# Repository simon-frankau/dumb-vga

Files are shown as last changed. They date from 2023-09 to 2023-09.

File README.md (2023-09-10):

# A simple flash-based VGA display

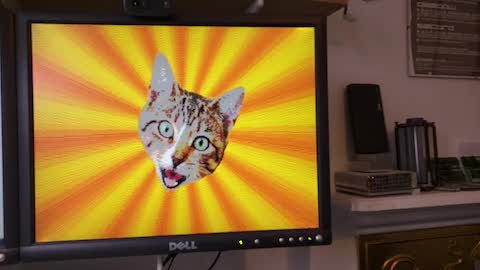
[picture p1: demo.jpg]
A picture of a cat's head, surrounded by a kind of sunburst pattern, being displayed on a montior


The idea of this project is to generate a basic VGA-like signal that a
monitor will display by putting the signal in a flash memory, and then
using counters to run through the address space. Simple, eh?

## VGA signal timing

We have h-sync and v-sync signals, with their respective front and
back porches. The main trick is the find a resolution that fits nicely
into a flash memory, so that the flash memory is a multiple of the
screen size - not the visible screen size, but the screen size with
all the sync bits.

A bit of twiddling gives a 384x240 visible display that is 512x256
once all the sync etc. is factored in.

## Clocking

A 32MHz clock is used as a dot clock for a 768x480 image at 60 FPS
(1024x512 when sync signals are factored in). The Flash cannot handle
a 32MHz data rate, but we clock it every other cycle and do scan-line
doubling to display a 384x240 image.

## VGA levels

H- and V-sync signals are straightforward to produce, as they're
apparently supposed to be TTL. That leaves 6 bits for 3 channels of
colour, or 2 bits per channel. A pair of resistors on each channel
makes the world's simplest DAC, with values chosen to give a 0.7V peak
when terminated by a 75 ohm resistor when both bits are set.

## Test pattern

gen_test.lua generates a simple RGB "checkerboard" displaying the
range of available colours.

gen_rom.lua generates a ROM image given a Gimp .data file (I couldn't
find a nice low-dep Lua image library). It simply takes the top two
bits of each pixel value to generate the colour.

prep_img.lua converts a .data image into another .data image that uses
the 6-bit colour space that the circuit can display. It uses dithering
to improve the generated image. Generating a ROM image from an image
that has been prepared with 'prep_img' should produce a rather better
result.

## Circuit design

The circuit breadboarded so far has three chained 74HC counters
supplying the address to a 29040 flash chip. A 74HC574 latches the
values for the display. (A 74HC574 triggers on the wrong edge to avoid
transients, but it's what I had to hand, and seems to work fine.)

## PCB

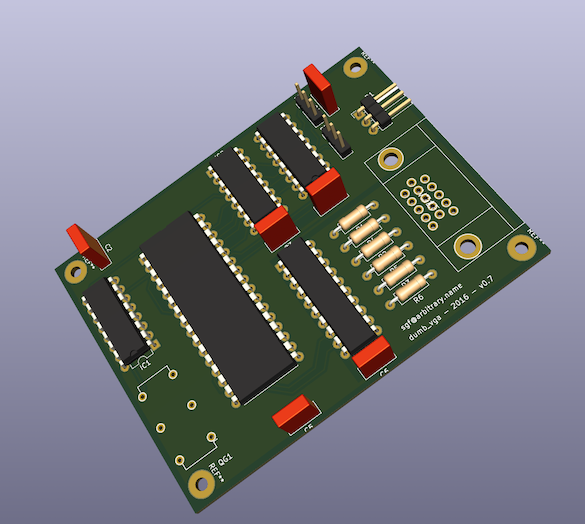
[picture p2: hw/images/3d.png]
A 3D render of the PCB


I sent the files in hw/gerbers to http://smart-prototyping.com/, and
they quickly sent me back PCBs which did the job. There are PDFs of
the Gerbers in hw/images.

### Assembly notes

The PCB is pretty straightforward to assemble (no surface mount!) as
long as you pay attention to the orientations, as I oriented things to
make routing easy, rather than assembly.

There should be enough space for a ZIF for the flash chip, although I
only used an IC socket.

The PCB has been designed to support 8-pin-sized oscillators as well
as 14-pin-sized oscillators. However, I installed the larger size.
Take a careful look at the PCB to see how to install the smaller
crystal if that's what you have. Check that power and ground reach the
appropriate pins.

Note that pin 1 of the power connector is ground, and pin 3 is Vcc.
This is something I wasn't paying attention to when setting up the
schematic (nor did I label it on the silkscreen).

### Animation speed

There are two headers on the board that you can jumper to set the
animation speed. They look like this:

```
 . . .   . . .
   P3      P2
```

The possibilities are:

```
 === .   === . Slow

 === .   . === Medium

 . ===   . === Fast
```

Note that only "medium" displays the 4 frames in the order they are in
memory (i.e. 1 2 3 4 1 2 3 4 ...). In the other two modes, the order
is 1 3 2 4 1 3 2 4 ... (if you're wondering why, it's because the
2-bit counter is bit-reversed). You will need to take this into
account when programming your animations.

## ROM image generation

The 'build.sh' script will generate a nice spinny [Bad Advice
cat](http://knowyourmeme.com/memes/bad-advice-cat) ROM image. If
you're using medium-speed mode, you'll need to pass the 'swap' flag.

I was originally hoping to script up the image wrangling mostly in
Gimp, but it turns out the script-fu support is rubbish. You can't
even [load a raw .data file in a non-interactive
script](https://github.com/marcelteun/GIMP-raw-file-load/blob/5f02e7607b1645d54b11bb9f01d44e362abca2d1/file-raw-load.c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).
So, it's just raw data files.

cat.data.gz was generated from cat.png using the Gimp interactively.
Which was me just scrubbing the background off the Bad Advice Cat
image. Minor copyright infringement is probably involved.

If you want to create your own image, I'm sure you can work out how to
do it by looking at build.sh and the lua scripts.

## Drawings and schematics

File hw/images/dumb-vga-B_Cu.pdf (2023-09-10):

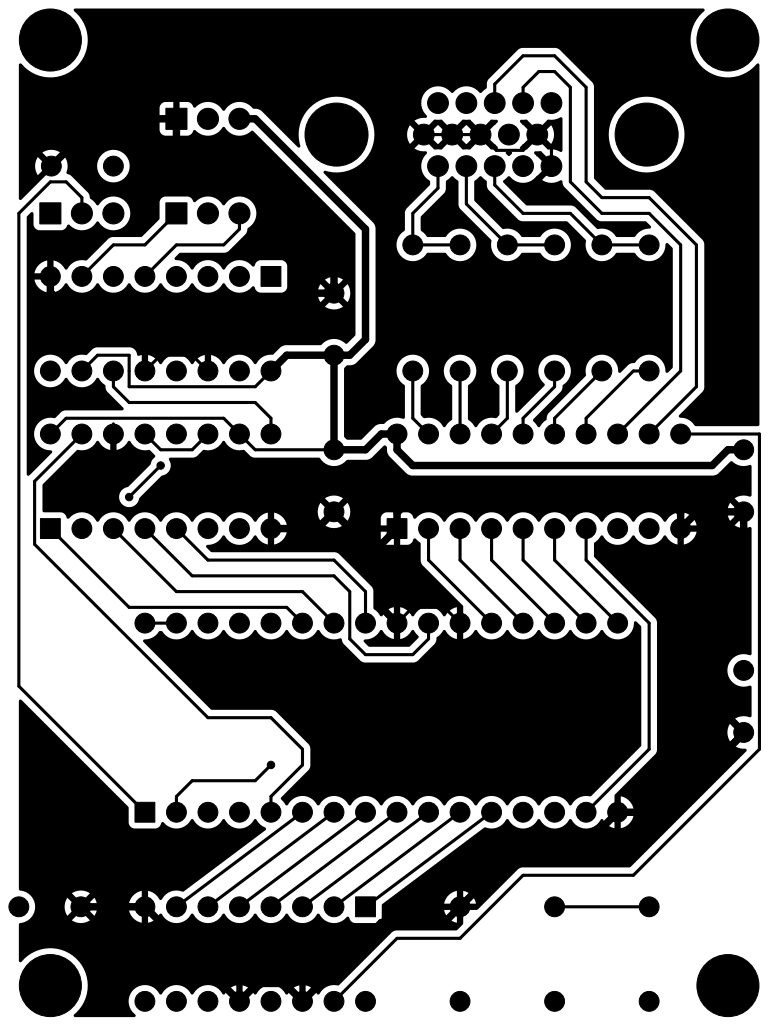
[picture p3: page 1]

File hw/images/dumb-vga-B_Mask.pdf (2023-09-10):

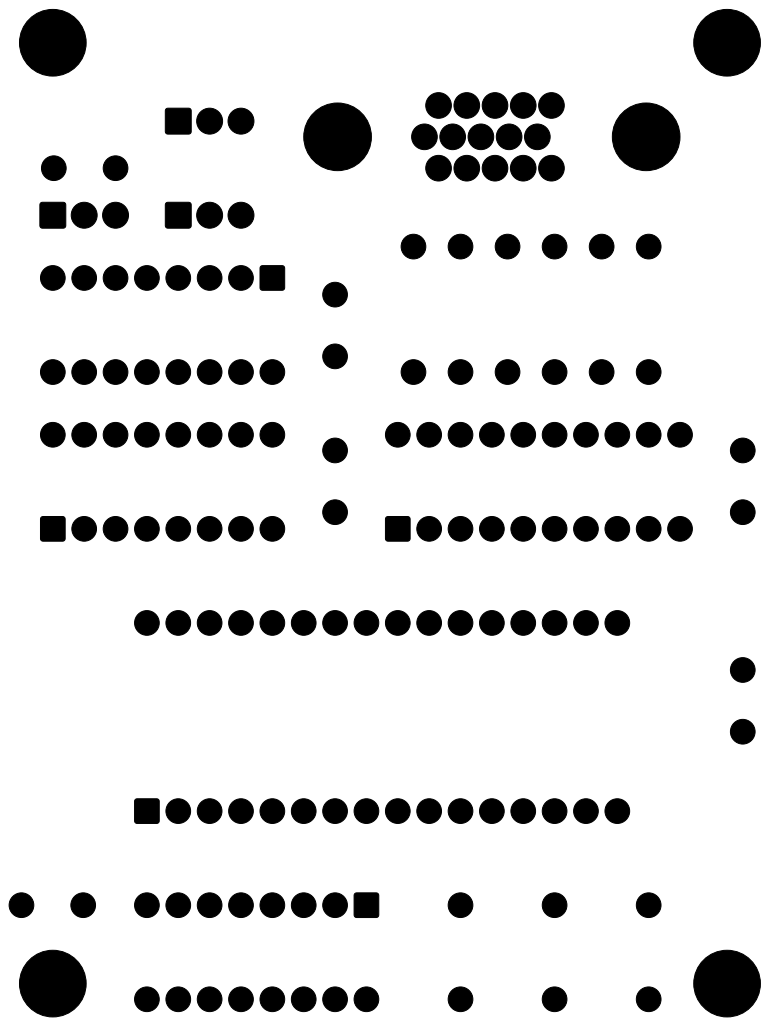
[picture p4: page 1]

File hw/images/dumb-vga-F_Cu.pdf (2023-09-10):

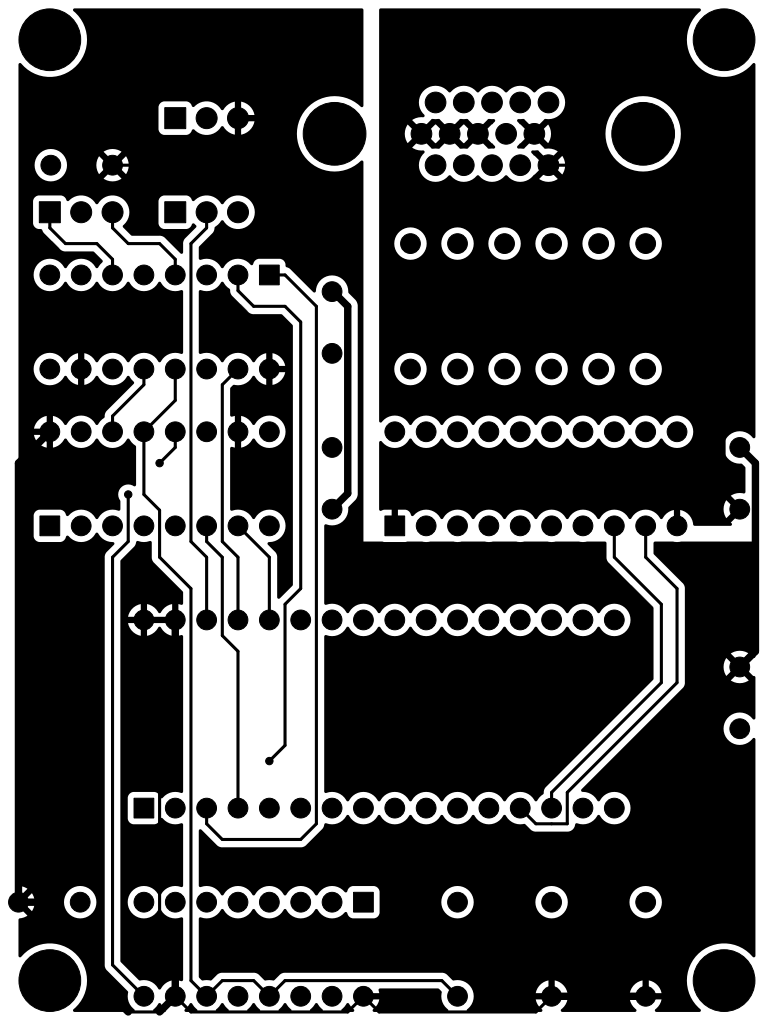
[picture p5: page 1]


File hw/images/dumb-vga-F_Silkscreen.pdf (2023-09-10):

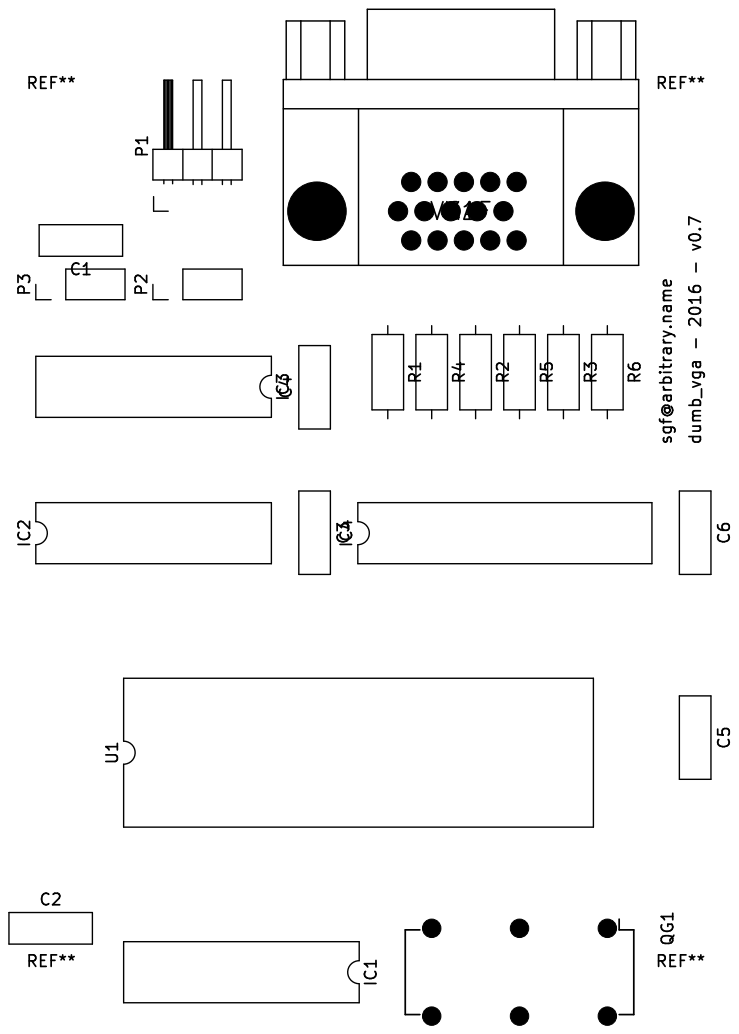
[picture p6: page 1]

dumb_vga - 2016 - v0.7 sgf@arbitrary.name C1 IC1 IC2 IC3 IC4 R1 R4 R2 R5 R3 R6 U1 VGAF X1

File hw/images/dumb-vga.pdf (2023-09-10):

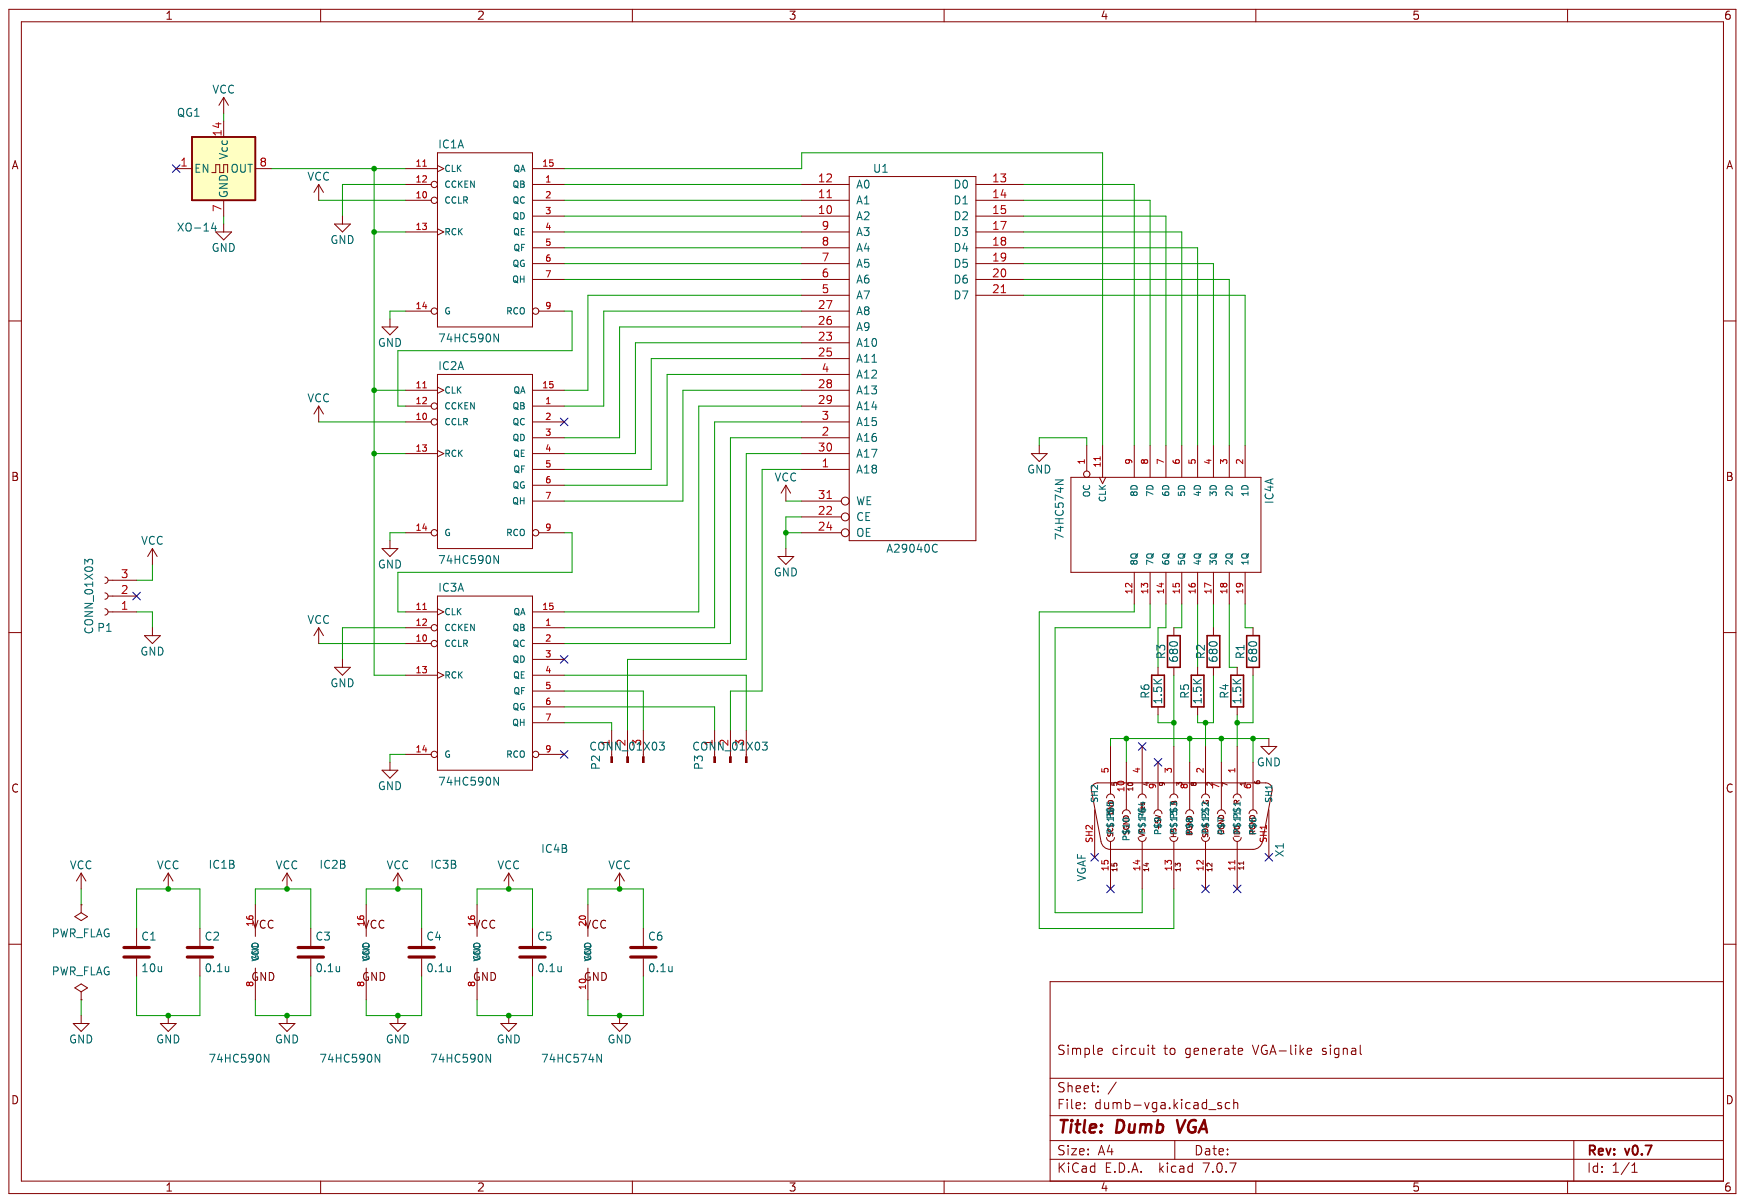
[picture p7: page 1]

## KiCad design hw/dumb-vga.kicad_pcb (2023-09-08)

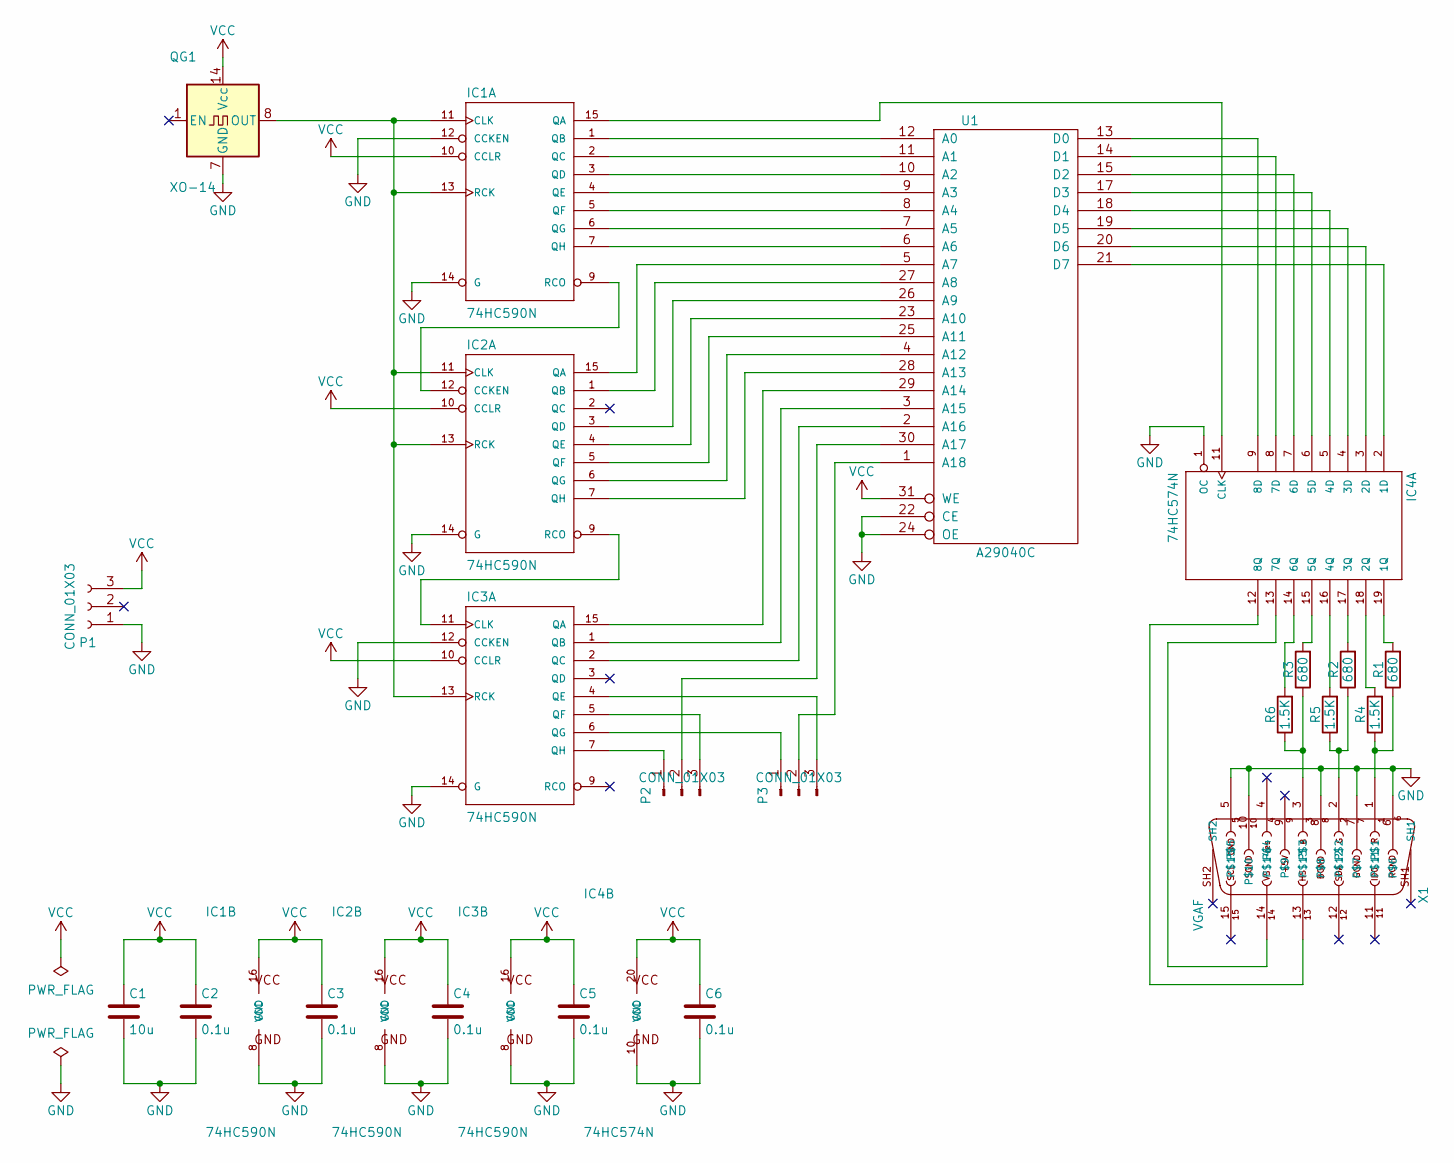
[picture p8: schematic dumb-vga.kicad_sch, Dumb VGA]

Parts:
C1: 10u; C_Rect_L7_W2.5_P5
C2, C3, C4, C5, C6: 0.1u; C_Rect_L7_W2.5_P5
IC1, IC2, IC3: 74HC590N; DIP-16_W7.62mm
IC4: 74HC574N; DIP-20_W7.62mm
P1: CONN_01X03; Pin_Header_Angled_1x03
P2, P3: CONN_01X03; Pin_Header_Straight_1x03
QG1: XO-14; xo-8-14
R1, R2, R3: 680; Resistor_Horizontal_RM10mm
R4, R5, R6: 1.5K; Resistor_Horizontal_RM10mm
U1: A29040C; DIP-32_W15.24mm
X1: VGAF; hd15f

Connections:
GND: C1.2, C2.2, C3.2, C4.2, C5.2, C6.2, IC1.8 (GND), IC1.12 (CCKEN), IC1.14 (G), IC2.8 (GND), IC2.14 (G), IC3.8 (GND), IC3.12 (CCKEN), IC3.14 (G), IC4.1 (OC), IC4.10 (GND), P1.1, QG1.7 (GND), U1.16 (GND), U1.22 (CE), U1.24 (OE), X1.5, X1.6, X1.7, X1.8, X1.10
unnamed: IC1.11 (CLK), IC1.13 (RCK), IC2.11 (CLK), IC2.13 (RCK), IC3.13 (RCK), QG1.8 (OUT)
unnamed: IC1.15 (QA), IC4.11 (CLK)
unnamed: IC1.1 (QB), U1.12 (A0)
unnamed: IC1.2 (QC), U1.11 (A1)
unnamed: IC1.3 (QD), U1.10 (A2)
unnamed: IC1.4 (QE), U1.9 (A3)
unnamed: IC1.5 (QF), U1.8 (A4)
unnamed: IC1.6 (QG), U1.7 (A5)
unnamed: IC1.7 (QH), U1.6 (A6)
unnamed: IC1.9 (RCO), IC2.12 (CCKEN)
unnamed: IC2.15 (QA), U1.5 (A7)
unnamed: IC2.1 (QB), U1.27 (A8)
unnamed: IC2.3 (QD), U1.26 (A9)
unnamed: IC2.4 (QE), U1.23 (A10)
unnamed: IC2.5 (QF), U1.25 (A11)
unnamed: IC2.6 (QG), U1.4 (A12)
unnamed: IC2.7 (QH), U1.28 (A13)
unnamed: IC2.9 (RCO), IC3.11 (CLK)
unnamed: IC3.15 (QA), U1.29 (A14)
unnamed: IC3.1 (QB), U1.3 (A15)
unnamed: IC3.2 (QC), U1.2 (A16)
unnamed: IC3.4 (QE), P3.3
unnamed: IC3.5 (QF), P2.3
unnamed: IC3.6 (QG), P3.1
unnamed: IC3.7 (QH), P2.1
unnamed: IC4.2 (1D), U1.21 (D7)
unnamed: IC4.19 (1Q), R1.2
unnamed: IC4.3 (2D), U1.20 (D6)
unnamed: IC4.18 (2Q), R4.2
unnamed: IC4.4 (3D), U1.19 (D5)
unnamed: IC4.17 (3Q), R2.2
unnamed: IC4.5 (4D), U1.18 (D4)
unnamed: IC4.16 (4Q), R5.2
unnamed: IC4.6 (5D), U1.17 (D3)
unnamed: IC4.15 (5Q), R3.2
unnamed: IC4.7 (6D), U1.15 (D2)
unnamed: IC4.14 (6Q), R6.2
unnamed: IC4.8 (7D), U1.14 (D1)
unnamed: IC4.13 (7Q), X1.14
unnamed: IC4.9 (8D), U1.13 (D0)
unnamed: IC4.12 (8Q), X1.13
unnamed: P2.2, U1.30 (A17)
unnamed: P3.2, U1.1 (A18)
unnamed: R1.1, R4.1, X1.1
unnamed: R2.1, R5.1, X1.2
unnamed: R3.1, R6.1, X1.3
VCC: C1.1, C2.1, C3.1, C4.1, C5.1, C6.1, IC1.10 (CCLR), IC1.16 (VCC), IC2.10 (CCLR), IC2.16 (VCC), IC3.10 (CCLR), IC3.16 (VCC), IC4.20 (VCC), P1.3, QG1.14 (Vcc), U1.31 (WE), U1.32 (VCC)

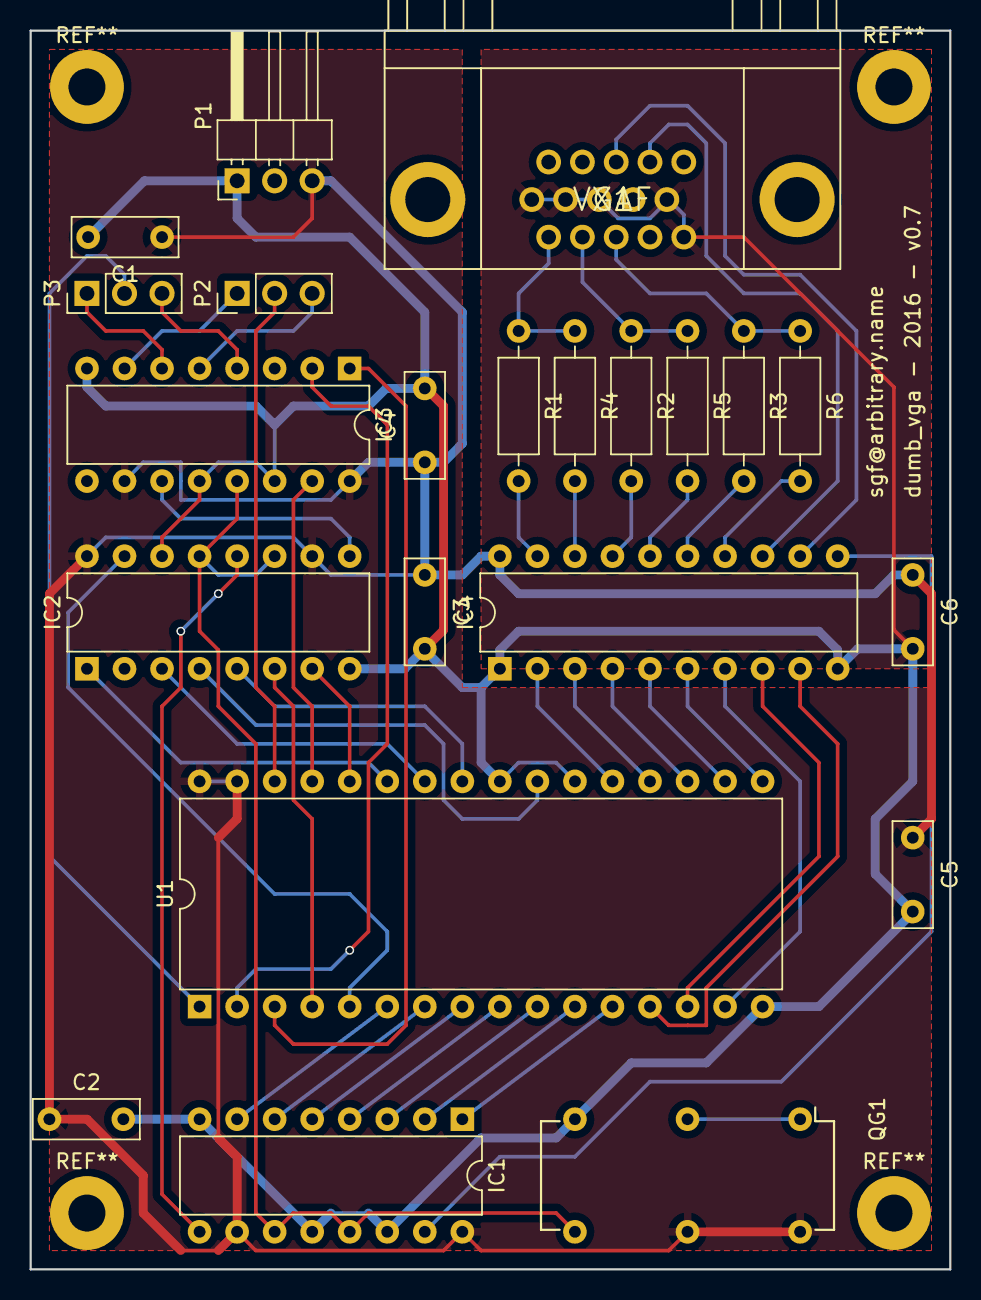
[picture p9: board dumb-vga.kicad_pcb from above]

Board: 2 copper layers, 62.2 x 83.8 mm, 22 parts (0 on the bottom side), 48 nets.

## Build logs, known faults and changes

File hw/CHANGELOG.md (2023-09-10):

# v0

Very first circuit I created. Low frequency (2MHz), has a few problems
(black stripes between the wide "pixels").

Note that the R and B channels are swapped around compared to what I
actually built (and thus what I wrote scripts for), as it's equivalent
and makes the schematic a lot easier to draw.

# v0.1

I added a 74574 latch to the output, so that the transients from the
output of the Flash aren't sent over the VGA lines, which resulted in
black stripes on the screen.

74574 = no stripes. Hurrah!

# v0.2

Switched from 2MHz oscillator to 16MHz oscillator, making the pixels
8x narrower. A 32MHz oscillator would give square pixels, but the
29040 takes 55ns to read, so that would be too fast.

Oscilloscope output looked good, but video didn't display. The
oscillator's output didn't look like a great square wave, but putting
an inverter or two on the 74754 latch's clock line made the display
work. It's not totally clear to me if this was because it helped
square up the wave, or perhaps because it fixed up a clock phase issue
- I need to investigate more.

By attaching the high address line to the highest bit of the counter,
we can create a simple animation with 2 frames.

# v0.3

Moved the inverter to directly after the oscillator. The display
works. This suggests that it's the signal shape, not phase issues
between different chips, that causes the problem. It seems only the
latch is annoyed by the shape of the oscillator output being
insufficiently square.

# v0.4

This revision is an optimisation, removing the inverter. As the
problem was feeding the oscillator output directly into the latch, I
removed the oscillator and did it another way: Replace the 16MHz
oscillator with a 32MHz oscillator, move all the address pins along to
get the same frequency counting, and use the lowest bit of the counter
as the clock for the latch. It seems to do the trick.

A downside is that the animation now only runs at twice the speed as
before (a bit manic), but it's a trade-off I'm willing to take to
eliminate a whole IC from a small design.

# v0.5

Rearranged the counter to perform scan-line doubling, which gives us
space for 4 frames in the Flash memory, as well as squarer pixels.

# v0.6

Added jumpers to allow control of the animation rate.

# v0.7

Swapped data lines around to simplify PCB routing.

# v0.8

Update to newer version of Kicad.

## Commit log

2016-03-05 v0 Schematic - very first circuit I built
    [dumb-vga.kicad_pcb, dumb-vga.sch]
2016-03-05 v0.1: Added 74574 buffer to eliminate black stripes
    [dumb-vga.sch]
2016-03-05 Update README.md to reflect schematic changes
2016-03-06 v0.2 Upped clock speed, added animation
    [dumb-vga.sch]
2016-03-06 v0.3 Moved inverter
    [dumb-vga.sch]
2016-03-06 Eliminated inverter
    [dumb-vga.sch]
2016-03-09 Updated README to current status of the project
2016-03-09 FIXME: Scan-line doubling
    [dumb-vga.sch]
2016-03-15 Add scan-line doubling
    [dumb-vga.sch]
2016-03-15 Add control over animation rate
    [dumb-vga.sch]
2016-03-15 Add note to improve resistor selection for better colour range
2016-03-16 Make animation rate switchable
    [dumb-vga.sch]
2016-03-16 Starting to design the PCB
    [dumb-vga.kicad_pcb]
2016-03-16 Rearranged memory lines to make PCB layout easier, laid out more PCB.
    [dumb-vga.kicad_pcb, dumb-vga.sch]
2016-03-16 Changed power connector for something I have
    [dumb-vga.kicad_pcb, dumb-vga.sch]
2016-03-17 PCB tidy-up
    [dumb-vga.kicad_pcb]
2016-03-18 Bumping schematic version number, labelling up PCB
    [dumb-vga.kicad_pcb, dumb-vga.sch]
2016-03-19 Switched to VGA connector with soldermask on the bottom
    [dumb-vga.kicad_pcb, dumb-vga.sch]
2016-03-19 Add generated Gerbers (set up for smart-prototyping.com)
    [dumb-vga.gbl, dumb-vga.gbs, dumb-vga.gtl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]
2016-04-06 Switch resistors around to make programming easier
    [dumb-vga.sch]
2016-04-06 Fixed scripts to work with final PCB design
2016-04-06 Update README.md in the face of practical PCB-assembly experience
2016-08-13 Remove extra, unnecessary, slow-loading libraries from the kicad .pro file.
2023-09-08 Update to new version of Kicad
    [dumb-vga.kicad_pcb, dumb-vga.kicad_sch, dumb-vga.sch]
2023-09-08 Move away from custom symbols, where convenient.
    Upgrading from an ancient version of Kicad left me with a bunch of
    symbosls in a local library that overlapped with the standard
    library. For the easy cases, I've tried to switch over. Where it would
    require rearranging lines on the schematic, I have not bothered.
    [dumb-vga.kicad_pcb, dumb-vga.kicad_sch]
2023-09-08 Move PCB onto standard footprints
    [dumb-vga.kicad_pcb, dumb-vga.kicad_sch]
2023-09-08 Update project-specific library
    [dumb-vga.kicad_sch]
2023-09-08 Rename the library, to no longer be "rescue".
    [dumb-vga.kicad_sch]
2023-09-10 Update Gerbers
    [dumb-vga.gbl, dumb-vga.gbs, dumb-vga.gtl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]
2023-09-10 Ooops, update version in schematic, too.
    [dumb-vga.kicad_sch]
